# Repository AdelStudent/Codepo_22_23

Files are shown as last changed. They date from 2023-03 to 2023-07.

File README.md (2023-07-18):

## Contents
- `main`: Code for Arduino
- `esp32_easy`: Code for ESP32
- `PCD codepo`: Used to share progress on the PCB
- `Report_final`: Used for writing monthly reports (code to transfer to Arduino)
- `projet codepo`: Used for reading different sensors (code to transfer to Arduino)
- `PythonTest`: Code permettant de vérifier l'envoie de message via le broker Thingstream
- `Modélisation Congo`: Modèle permettant de prédire la consommation en énergie de la cameskin
- `Data Type Cameskin`: Dossier que la CAMESKIN nous a partagé afin comparer si nos moyens de communiquer la data est pertinante

Voici quelques commandes git utiles:

### Download the project
- git clone https://github.com/AdelStudent/Codepo_22_23.git

### Update a downloaded code
- git status
- git pull

### Commit a new code!!
- git add .
- git commit -a -m "Update Message"
- git push

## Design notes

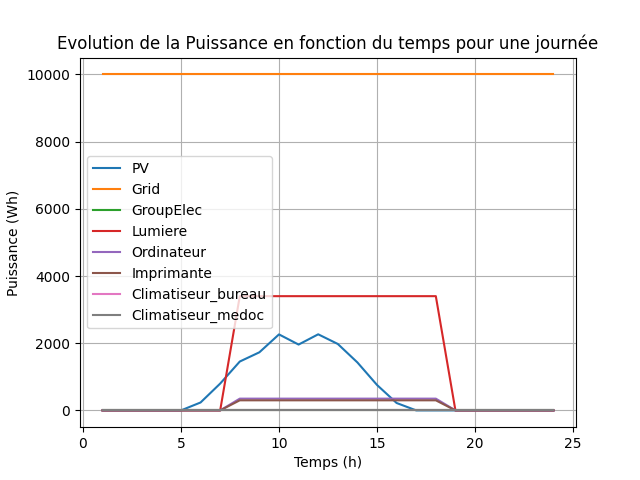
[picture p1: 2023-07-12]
Modélisation Congo/Evolution de la Puissance (1 journée).png

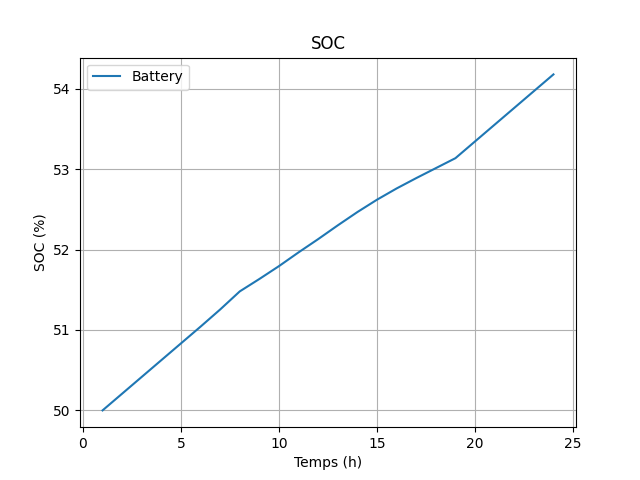
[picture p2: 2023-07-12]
Modélisation Congo/SOC.png

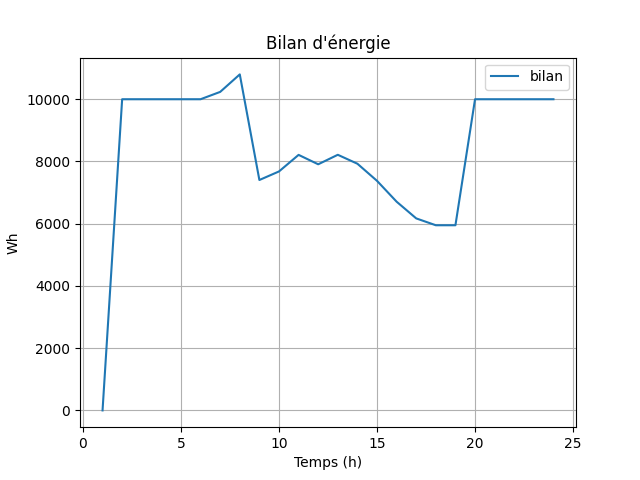
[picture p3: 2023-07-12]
Modélisation Congo/Bilan d'énergie.png

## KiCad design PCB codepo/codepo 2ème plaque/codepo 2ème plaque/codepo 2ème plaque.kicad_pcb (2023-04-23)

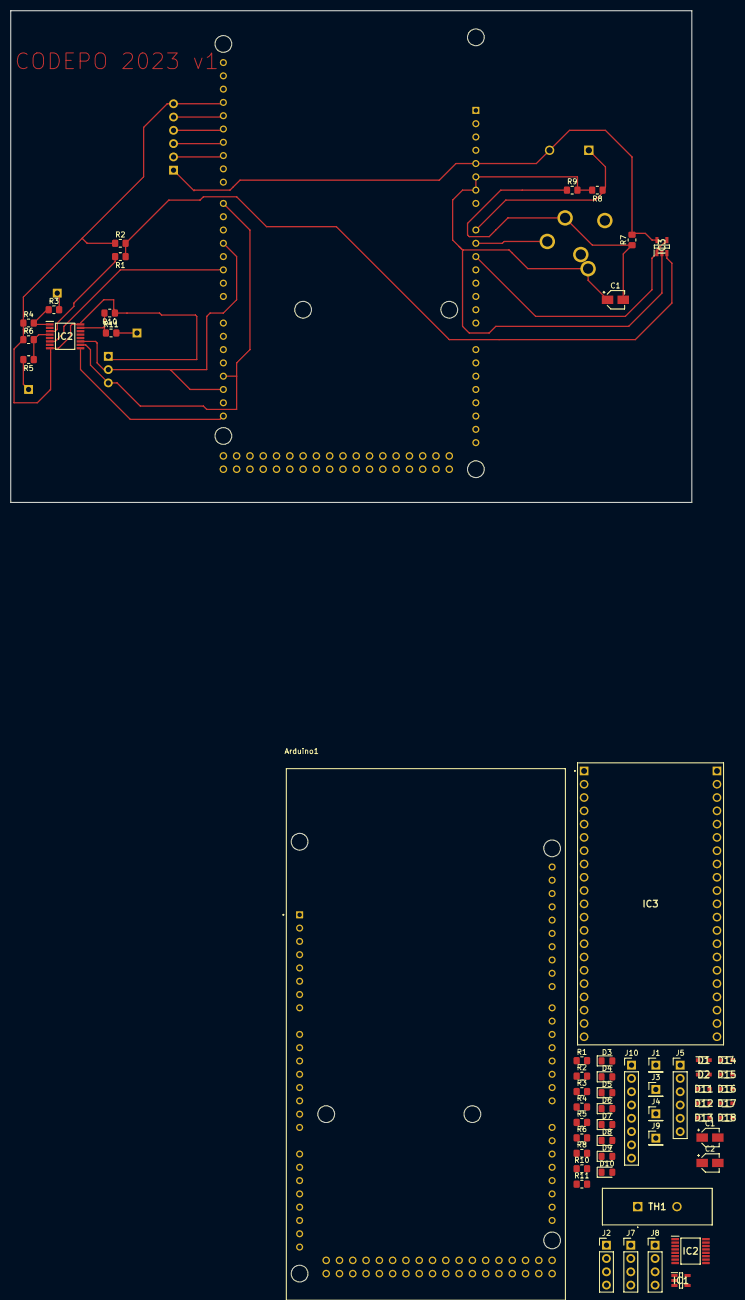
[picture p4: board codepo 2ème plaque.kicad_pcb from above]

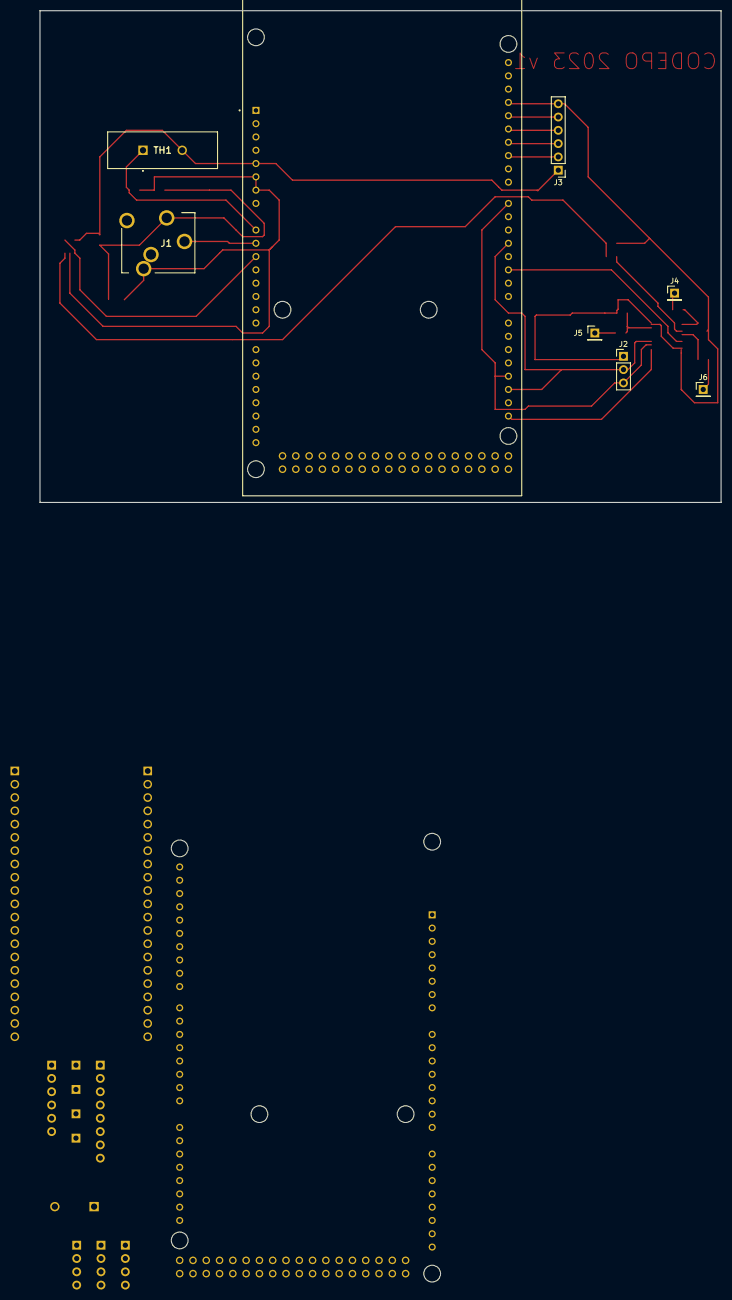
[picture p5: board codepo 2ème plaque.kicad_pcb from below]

Board: 2 copper layers, 130.2 x 94.0 mm, 65 parts (8 on the bottom side), 27 nets.

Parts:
Arduino1, Arduino1#2: DUE; MODULE_A000062
C1: 100 uF; CP_Elec_3x5.3
C1#2, C2: 0.1uF; CP_Elec_3x5.3
D1, D2, D11, D12, D13, D14, D15, D16, D17, D18: D_Schottky; SODFL2513X70N
D3, D4, D5, D6, D7, D8, D9, D10: D_Zener; D_0805_2012Metric_Pad1.15x1.40mm_HandSolder
IC1, IC3: OPA182IDBVR; SOT95P280X145-5N
IC2, IC2#2: TMUX4051PWR; SOP65P640X120-16N
IC3#2: ESP32-S2-Saola-1RI; ESP32S2Saola1RI
J1, J3, J4, J4#2, J5#2, J6, J9: Conn_01x01_Pin; PinHeader_1x01_P2.54mm_Vertical
J1#2: 35RAPC4BH3
J2, J7, J8: Conn_01x04_Pin; PinHeader_1x04_P2.54mm_Vertical
J2#2: Conn_01x03_Pin; PinHeader_1x03_P2.54mm_Vertical
J3#2, J5: Conn_01x06_Pin; PinHeader_1x06_P2.54mm_Vertical
J10: Conn_01x08_Pin; PinHeader_1x08_P2.54mm_Vertical
R1, R1#2: 910kohm; R_0805_2012Metric_Pad1.20x1.40mm_HandSolder
R2, R2#2: 270kohm; R_0805_2012Metric_Pad1.20x1.40mm_HandSolder
R3, R3#2, R10, R10#2, R11, R11#2: 910Kohm; R_0805_2012Metric_Pad1.20x1.40mm_HandSolder
R4, R4#2: 450kohm; R_0805_2012Metric_Pad1.20x1.40mm_HandSolder
R5, R5#2: 910 kohms; R_0805_2012Metric_Pad1.20x1.40mm_HandSolder
R6, R6#2: 300kohm; R_0805_2012Metric_Pad1.20x1.40mm_HandSolder
R7, R8, R8#2, R9: 10kohm; R_0805_2012Metric_Pad1.20x1.40mm_HandSolder
TH1, TH1#2: Thermistor_NTC; B57364S0300M000

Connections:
0: Arduino1.GND1, Arduino1.GND2, C1#2.1, D1.1 (K), D2.1 (K), D3.2 (A), D4.2 (A), D5.2 (A), D6.2 (A), D7.2 (A), D8.2 (A), D9.2 (A), D10.2 (A), D11.1 (K), D12.1 (K), D13.1 (K), D14.1 (K), D15.1 (K), D16.1 (K), D17.1 (K), D18.1 (K), IC1.2 (V-), IC2#2.2 (S6), IC2#2.5 (S5), IC2#2.8 (GND), IC2#2.14 (S1), IC3#2.22 (GND_2), J2.1, J5.6, J7.1, J8.1, J10.8, R2.1, R4#2.1, R6#2.1, R8.2, R10.1
5V: Arduino1.5V_1 (+5V_1), C2.1, J2.4, J5.5, J7.4, J8.4, TH1.2
unnamed: Arduino1.AD0 (ADC0), D3.1 (K), R8.1, TH1.1
unnamed: Arduino1.AD1 (ADC1), D4.1 (K), IC1.1 (OUT), IC1.4 (-IN)
unnamed: Arduino1.AD2 (ADC2), D5.1 (K), J2.2
unnamed: Arduino1.AD3 (ADC3), D6.1 (K), J2.3
unnamed: Arduino1.AD4 (ADC4), D7.1 (K), J8.2
unnamed: Arduino1.AD5 (ADC5), D8.1 (K), J8.3
unnamed: Arduino1.AD6 (ADC6), D9.1 (K), J7.2
unnamed: Arduino1.AD7 (ADC7), D10.1 (K), J7.3
unnamed: Arduino1.2 (D2), D11.2 (A), IC2#2.6 (~EN)
unnamed: Arduino1.16 (D16/TX2), D12.2 (A), IC3#2.26 (U0RXD)
unnamed: Arduino1.17 (D17/RX2), D13.2 (A), IC3#2.25 (GPIO45)
unnamed: Arduino1.7 (D7), Arduino1.18 (D18/TX1), Arduino1.21 (D21/SCL), D1.2 (A), D14.2 (A), D16.2 (A), IC2#2.9 (A2), IC2#2.10 (A1), J10.4
unnamed: Arduino1.4 (D4), Arduino1.19 (D19/RX1), D2.2 (A), D15.2 (A), IC2#2.11 (A0), J10.3
unnamed: Arduino1.52 (D52), D17.2 (A), J5.1
unnamed: D18.2 (A), IC1.3 (+IN), R1#2.1, R2.2
unnamed: C2.2, IC1.5 (V+)
unnamed: IC2#2.3 (D), R1#2.2
unnamed: IC2#2.15 (S2), R10.2, R11.1
unnamed: IC2#2.12 (S3), J9.1
unnamed: IC2#2.1 (S4), R3#2.1, R4#2.2
unnamed: IC2#2.4 (S7), R5.1, R6#2.2
unnamed: C1#2.2, IC2#2.16 (VDD)
unnamed: J1.1, R5.2
unnamed: J3.1, R3#2.2
unnamed: J4.1, R11.2

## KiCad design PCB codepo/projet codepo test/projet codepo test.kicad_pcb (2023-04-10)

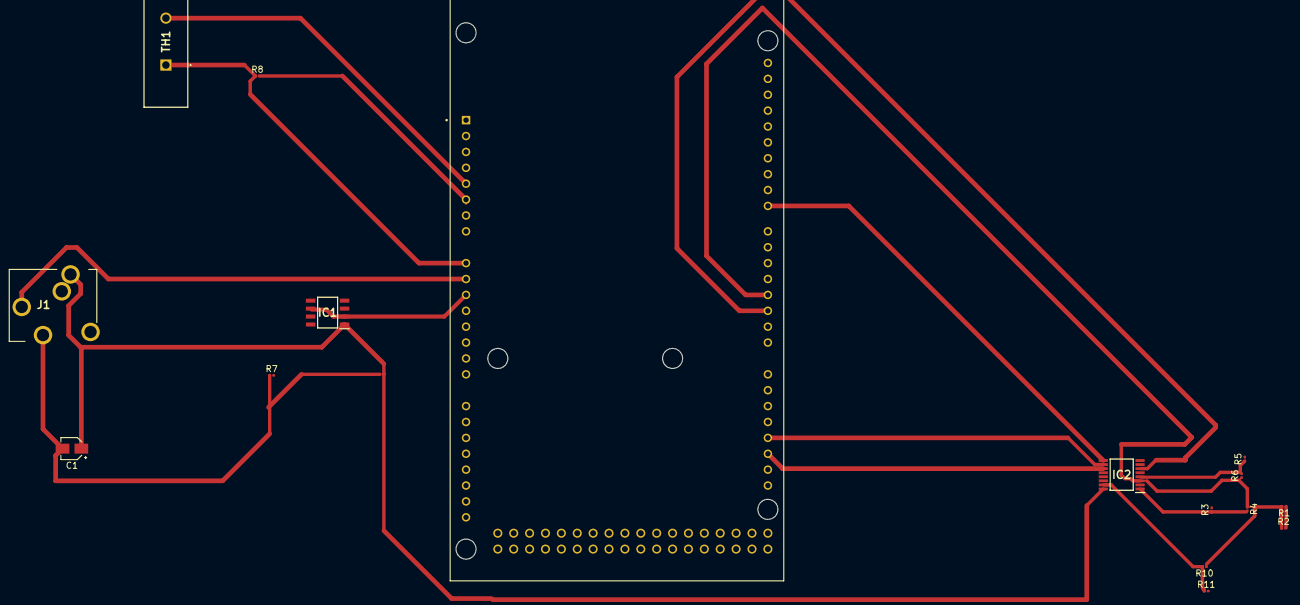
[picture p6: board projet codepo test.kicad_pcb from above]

Board: 2 copper layers, 17 parts (0 on the bottom side), 15 nets.

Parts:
Arduino1: DUE; MODULE_A000062
C1: 100 uF; CP_Elec_3x5.3
IC1: OPA182IDR; SOIC127P600X175-8N
IC2: TMUX4051PWR; SOP65P640X120-16N
J1: 35RAPC4BH3
R1: 910kohm; R_0201_0603Metric
R2: 270kohm; R_0201_0603Metric
R3, R10, R11: 910Kohm; R_0201_0603Metric
R4: 450kohm; R_0201_0603Metric
R5: 910 kohms; R_0201_0603Metric
R6: 300kohm; R_0201_0603Metric
R7, R8, R9: 10kohm; R_0201_0603Metric
TH1: Thermistor_NTC; B57364S0300M000

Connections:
0: Arduino1.3 (D3), IC2.3 (D), R1.2, R2.1, R4.1, R6.1, R10.1
unnamed: Arduino1.5V_1 (+5V_1), IC1.8 (V+), R7.2, TH1.2
unnamed: Arduino1.AD0 (ADC0), R8.1, TH1.1
unnamed: Arduino1.AD1 (ADC1), J1.1
unnamed: Arduino1.AD2 (ADC2), IC1.2 (-IN_A), IC1.6 (-IN_B)
unnamed: Arduino1.2 (D2), IC2.6 (~EN)
unnamed: Arduino1.8 (D8), IC2.9 (A2)
unnamed: Arduino1.7 (D7), Arduino1.18 (D18/TX1), IC2.10 (A1)
unnamed: Arduino1.4 (D4), Arduino1.19 (D19/RX1), IC2.11 (A0)
unnamed: C1.2, J1.5, R7.1, R9.1
unnamed: Arduino1.GND1, C1.1, IC1.1 (OUT_A), IC2.8 (GND), IC2.16 (VDD), J1.2, R8.2, R9.2
unnamed: IC2.15 (S2), R10.2, R11.1
unnamed: IC2.1 (S4), R3.1, R4.2
unnamed: IC2.4 (S7), R5.1, R6.2
unnamed: R1.1, R2.2

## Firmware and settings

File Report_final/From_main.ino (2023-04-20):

void SD_init(int *init_flag_SD){ //Le pointeur initial est à 0 si il y a une carte -> update to 1
  // Le pointeur est appelé flag car il indique si l'initialisation s'est fait correctement
  //print_variable("CS_PIN",CS_PIN);
  if(SD.begin(CS_PIN)==true){
    //Serial.println("La carte SD a bien démarrée");
    *init_flag_SD = 1;
  }
  else{
    Serial.println("La carte SD n'a PAS ete trouve!");
  }
}


void delete_file(String filename){
  //Si le file existe, on le supprime (utile pour les tests)
  if(verify_file_existing(filename)){ //vérifie d'abord que le fichier existe sur la carte 
  // correpond à une boucle if True
    SD.remove(filename);
    Serial.println("Report a été nettoyé");
  }
}
bool verify_file_existing(String filename){ //filename to be checked 
  //Si le file existe, on le supprime (utile pour les tests)
  if(SD.exists(filename)){
    Serial.println("Le file existe!");
    return true; //retourne une réponde boolean 
  }else{
    Serial.println("Le file n'existe pas.");
    return false; //retourne une autre réponse de boolean 
  }
}

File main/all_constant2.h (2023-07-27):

/*
Pour la personne qui va lire ce code:
    Ce fichier en .h ne sera appelé que par le header file "z_all_constantes". Cette méthode nous a permis de travailler en parallèle
    tout en faisant un merge aisé ainsi que nous permettant de nous y retrouver rapidement.
*/

//ECRAN LCD
#include "Wire.h"
#include "LiquidCrystal_I2C.h"

LiquidCrystal_I2C LCD(0x27,16,2);

//PINS
  //A0 -> thermistance 
  //A1 -> mesure courant 
  //A2 -> calibration capteur de courant 
  //A3 -> sortie du multiplexeur 
  //2 -> ENpin du multiplexeur 
  //4 -> Decision de channel du multi
  //7 -> Decision de channel du multi
  //8 -> Decision de channel du multiSOC_init
//___________________THERMISTANCE___________________//
#define Tsensor A0

float A = 2.51e-03, B =1.039e-04, C = 0; //Coef. permettant de déterminer la température grâce 
#define THERMISTOR 10000 // résistance nominale de la thermistor, 10 kOhm
#define Vcc 3.3// tension d'entrée= 3.3V


//_________________Capteur COURANT_________________//
  //AC & DC Current Sensor with LCD By Solarduino 
  //AC & DC current captor -> HSTS016L Hall effect split core current transformer
  //The current measured is the Root Mean Square (RMS) value.

int decimalPrecision = 4; //Precision -> nombre de décimales 

//_________________PINS
int currentAnalogInputPin = A1;    // Pin to measure Current Value -> celle connecté au sensor [JAUNE]
int calibrationPin = A2;         // Pin to calibrate offset middle value -> calibre le senseur [BLANC]

//_________________Variables
float manualOffset = 0;  //0.26 -0.37  0.280    // Key in value to manually offset the initial value -> Pourrait l'utiliser si on arrive vraiment pas à ce qu'on veut 
// pour ajuster manuellement la lecture du courant initiale si nécessaire 
float mVperAmpValue = 31.25; //31.25 -20.83    // mVperAmp = maximum voltage range (in milli volt) / current rating of CT
//Specifie le mV/A puissance du transformateur de courant 
// For a 20A Hall-Effect Current Transformer rated at 20A, 2.5V +/- 0.625V, mVperAmp will be 625 mV / 20A = 31.25mV/A 

float supplyVoltage = 3300;        // Analog input pin maximum supply voltage, Arduino Uno or Mega is 5000mV while Arduino Nano or Node MCU is 3300mV
// Interessant de noter que toutes les données sont en mV
//Maximum tension d'entrée aux pins analogue de l'Arduino  
float offsetSampleRead = 0;        // to read the value of a sample for offset purpose later 
//Pour lire une valeur échantillon pour déterminer le décalage de/par rapport calibration 
float currentSampleRead  = 0;      // to read the value of a sample including currentOffset1 value
//Utiliser pour lire la valeur de courant pour chaque échantillon 
float currentLastSample  = 0;      //to count time for each sample. Technically 1 milli second 1 sample is taken 
//Pour tracker le temps depuis que le dernier échantillon a été pris 
float currentSampleSum   = 0;      // accumulation of sample readings 
//Accumulate les valeurs échantillons 
float currentSampleCount = 0;      // to count number of sample. 
float currentMean ;                // to calculate the average value from all samples, in analog values
float RMSCurrentMean ;             // square roof of currentMean, in analog values  
float FinalRMSCurrent ;            // the final RMS current

//_____CAPTEUR DE TENSION/MULTIPLEXEUR___________//
  // basé sur le code https://www.aranacorp.com/fr/utilisation-dun-multiplexer-avec-arduino/
  
//_________________CONSTANTS
#define number_of_mux 1 //définition du nombre de multiplexeur
#define numOfMuxPins number_of_mux * 8 //définition du nombre de pins totals (en fonction du nombre de multiplexeur)

//_________________PINS
  //Pins qui indique les portes à ouvrir sur l'Arduino
#define enPin 2 //Quand cette pin est high, tous les switchs sont off 
#define channelA0 4 //pin A0 du mult (11 sur mult) -> pin 4 digital de l'Arduino
#define channelA1 7 //pin A1 du mult (10 sur mult) -> pin 7 digital de l'Arduino
#define channelA2 8 // pin A2 du mult (9 sur mult) -> pin 8 digital de l'Arduino

//Tension de sortie que l'on veut mesuré après le montage avec diviseur résistif 
#define pinout A3  // pin analogue A1

float measured_value[] = {0,0,0,0,0,0,0,0}; //vecteur qui prend les valeurs 
//i ème position du vecteur sera égale à la valeur mesuré sur la ième porte 

//Paramètre
const int D  = 3; //Drain pin, allows to send/receive signals. Connecté selon les indications du site

//_________________PARAMETRES PROTOTYPE
float R1 = 913, R2 = 280;//en kohm 
// à corriger avec ce qui est lu par le multimètre : pas 907 et 270 mais 913 et 280

//#define Vcc 5.0 // tension d'entrée= 5.0V
//=> Déjà définie pour la thermistance
//De l'année passée
int nbSamples = 100;
double mvPerI_20 = 31.25;
double offset_20 = 0.36;
double mvPerI_100 = 6.25;
double offset_100 = 1.6;
double mvPerI_30 = 20.83;
double offset_30 = 0.515;
double offset_30_bat020 = 0.515;//0.16
double offset_30_res020 = 0.515;//0.27
double offset_30_ppv020 = 0.515;//0.31

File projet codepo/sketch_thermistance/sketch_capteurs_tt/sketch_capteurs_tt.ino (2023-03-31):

//code pour la tension
float R1 = 907, R2 = 270;//en kohm
float A = 8.79e-03, B = -1.1e-03, C = 6.46e-06;
#define THERMISTOR 10000 // résistance nominale de la thermistor, 10 kOhm

#define sensor A0
#define Vcc 5.0 // tension d'entrée= 5V
#define pinout A2
const int s0Pin = 2; // connect to S0 pin of TMUX1108
const int s1Pin = 3; // connect to S1 pin of TMUX1108
const int s2Pin = 4; // connect to S2 pin of TMUX1108
const int s3Pin = 5; // connect to S3 pin of TMUX1108
#define pinout A2// connect to the Vo pin of TMUX1108
#include <Wire.h>
#include <EmonLib.h>

EnergyMonitor emon1;
int tension = 9.38; //itier la tension (calculer au préalable avec un multimetre)
#define pin_sct A1// pin A1 =connexion au capteur

void setup() {
  Serial.begin(9600);
  emon1.current(pin_sct, 29);
  pinMode(sensor, INPUT);
  pinMode(pinout, INPUT);
  pinMode(s0Pin, OUTPUT);
  pinMode(s1Pin, OUTPUT);
  pinMode(s2Pin, OUTPUT);
  pinMode(s3Pin, OUTPUT);
  pinMode(pinout, INPUT);

  // set initial state for multiplexer pins
  digitalWrite(s0Pin, LOW);
  digitalWrite(s1Pin, LOW);
  digitalWrite(s2Pin, LOW);
  digitalWrite(s3Pin, LOW);
}

void loop() {
  // read Vo from currently selected input
  double Vo = analogRead(pinout) / 1023.0 * 3.3;
  double Vin = Vo * (R1 + R2) / R2;
  Serial.print("vout=");
  Serial.print(Vo);
  Serial.print("V");

  Serial.print("vin=");
  Serial.print(Vin);
  Serial.println("V");
  // select next input
  int s3 = digitalRead(s3Pin);
  int s2 = digitalRead(s2Pin);
  int s1 = digitalRead(s1Pin);
  int s0 = digitalRead(s0Pin);

  if (s3 == LOW && s2 == LOW && s1 == LOW && s0 == LOW) {
    digitalWrite(s0Pin, HIGH);
  } else if (s3 == LOW && s2 == LOW && s1 == LOW && s0 == HIGH) {
    digitalWrite(s0Pin, LOW);
    digitalWrite(s1Pin, HIGH);
  } else if (s3 == LOW && s2 == LOW && s1 == HIGH && s0 == LOW) {
    digitalWrite(s1Pin, LOW);
    digitalWrite(s2Pin, HIGH);
  } else if (s3 == LOW && s2 == LOW && s1 == HIGH && s0 == HIGH) {
    digitalWrite(s2Pin, LOW);
    digitalWrite(s3Pin, HIGH);
  } else if (s3 == LOW && s2 == HIGH && s1 == LOW && s0 == LOW) {
    digitalWrite(s1Pin, HIGH);
    digitalWrite(s2Pin, LOW);
    digitalWrite(s3Pin, LOW);
  } else if (s3 == LOW && s2 == HIGH && s1 == LOW && s0 == HIGH) {
    digitalWrite(s0Pin, HIGH);
    digitalWrite(s2Pin, LOW);
    digitalWrite(s3Pin, LOW);
  } else if (s3 == LOW && s2 == HIGH && s1 == HIGH && s0 == LOW) {
    digitalWrite(s0Pin, LOW);
    digitalWrite(s1Pin, HIGH);
    digitalWrite(s3Pin, LOW);
  } else if (s3 == LOW && s2 == HIGH && s1 == HIGH && s0 == HIGH) {
    digitalWrite(s0Pin, HIGH);
    digitalWrite(s1Pin, HIGH);
    digitalWrite(s2Pin, HIGH);
    digitalWrite(s3Pin, LOW);
  } else if (s3 == HIGH && s2 == LOW && s1 == LOW && s0 == LOW) {
    digitalWrite(s2Pin, HIGH);
    digitalWrite(s1Pin, LOW);
    digitalWrite(s0Pin, LOW);
  } else if (s3 == HIGH && s2 == LOW && s1 == LOW && s0 == HIGH) {
    digitalWrite(s3Pin, LOW);
    digitalWrite(s1Pin, LOW);
    digitalWrite(s0Pin, HIGH);
  } else if (s3 == HIGH && s2 == LOW && s1 == HIGH && s0 == LOW) {
    digitalWrite(s2Pin, HIGH);
    digitalWrite(s0Pin, LOW);
  } else if (s3 == HIGH && s2 == LOW && s1 == HIGH && s0 == HIGH) {
    digitalWrite(s3Pin, LOW);
    digitalWrite(s0Pin, HIGH);
  } else if (s3 == HIGH && s2 == HIGH && s1 == LOW && s0 == LOW) {
    digitalWrite(s3Pin, LOW);
    digitalWrite(s1Pin, HIGH);
  } else if (s3 == HIGH && s2 == HIGH && s1 == LOW && s0 == HIGH) {
    digitalWrite(s2Pin, LOW);
    digitalWrite(s1Pin, HIGH);
    digitalWrite(s0Pin, HIGH);
  } else if (s3 == HIGH && s2 == HIGH && s1 == HIGH && s0 == LOW) {
    digitalWrite(s3Pin, LOW);
    digitalWrite(s2Pin, HIGH);
    digitalWrite(s0Pin, LOW);
  } else if (s3 == HIGH && s2 == HIGH && s1 == HIGH && s0 == HIGH) {
    digitalWrite(s3Pin, HIGH);
  }
  int sensorvalue = analogRead(sensor);
  float Vx = sensorvalue * (5.0 / 1023.0);
  float V = Vcc - Vx;
  float I = Vx / 10000;
  float R = V / I;
  Serial.print("R=");
  Serial.print(R);
  Serial.print("ohm");
  Serial.print(", t=");

  float steinhart;
  float T;
  steinhart = 1 / (A + (B * log(R)) + (C * pow((log(R)), 3)));
  T = steinhart - 273.15; //pour tourner la température en degré
  Serial.print(T);
  Serial.println("°C");
  double Irms = emon1.calcIrms(1480);
  Serial.print("Courant:"); //(en ampère)
  Serial.println(Irms);


  delay(1000);
}

////This code uses digital pins 2-5 to control the select lines of the TMUX1108 multiplexer
////and analog pin A0 to read the Vo from the selected input. The `loop()` function cycles
////through all 16 input channels of the multiplexer, reading the Vo from each one in turn.
////The debounce delay of 10ms helps to reduce noise and stabilize the Vo readings.

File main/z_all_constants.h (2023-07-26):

/*
Pour la personne qui va lire ce code:
    Ce header file (.h) permet d'avoir un fichier aillant tous les includes/constantes nécessaires au bon déroulement de notre protoype.
    Cela permet surtout une lecture plus aisée du projet.
*/
#include "all_constant2.h"

#include <SD.h>
#include <SPI.h>
#include "TimeLib.h"
#include "time.h"

#include "RTClib.h" //Downloaded from the follwoing git : https://github.com/adafruit/RTClib
                    //Also needed this one : https://github.com/adafruit/Adafruit_BusIO/tree/master
#include <RTCDue.h>



#include <LiquidCrystal.h>

#include <stdlib.h>



////////////////////////////////////////////////////////////////////
//Initialisation des variables                                    //
////////////////////////////////////////////////////////////////////

//_____________________Kalman Variables___//

//_____________________Multi Threading version Wish___//
unsigned long lastMeasurementTime = 0; // variable to store the last time measurement
unsigned long lastHearingTime = 0; // variable to store the last time we heard Arduino
unsigned long lastReportWriting = 0; // variable to store the last time we wrote into the Arduino
unsigned long lastAskingTime = 0; // variable to store the last time we asked IP address to ESP32
unsigned long lastUpdateFilter = 0; //variable to store the last time Kalman Filter parameters update
unsigned long last_warning_message = 0; //variable to store the last time we send potentially send a Warning Mail



//_____________________Thingstream___________________//
unsigned long mytime; //Permet de connaitre le temps d'attente pour recevoir une réponde du thingStream
int init_flag = 0;  //Permet de savoir si toutes les étapes de l'initialisation du Thingstream sont okay
bool already_publish = false; //Variable tests

//_____________________SD Card______________________//
File myFile;  //Objet permettant l'ouverture de fichiers en accès w et/ou r
File myReport;  //Par souçis de cohérence des parties de codes, on garde ces Files
File file;  //Par soucis de cohérence des parties de codes, on garde les 3 files (myFile/myReport/file)
#define CS_PIN 53 //Pin utilisée pour transmettre la data à la carte SD
int init_flag_SD = 0;


//_____________________ESP32______________________//
String esp32_ip = "";
bool answering_mode = false; //It allows to block send any queries to ESP32 if this mode is activated
unsigned long answering_mode_chrono = 0; // variable to store the time of the last time we asked IP address to ESP32

//_____________________Measures______________________//
// Define the input and output pins for the current sensors
#define INPUT_CURRENT_PIN A0
#define OUTPUT_CURRENT_PIN A1
// Define the sample interval (in milliseconds) and the number of samples to take
#define SAMPLE_INTERVAL 1000
#define NUM_SAMPLES 10

//_______________Coulomb Counting___________________//
float SOC_init = 0.97; // We only need a start point

// Define a variable to keep track of the last sample time
unsigned long lastSampleTime = 0;

//_____________________CLOCK________________________//
RTCDue Arduino_rtc(XTAL); //Arduino RTC
RTC_DS3231 rtc; //DS3231 RTC

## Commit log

2023-07-07 Add files via upload
    Checking periodically if the ESP32 got disconnected to the Wifi.
2023-07-08 Vcc Tension
2023-07-08 Réajustement des résistances
2023-07-10 Nouvel fonction de mesure de courant
2023-07-10 Constantes pour le capteur de courant
2023-07-13 Resistance des diviseurs résistifs measure.ino
2023-07-13 Arduino answering_mode + corrections
    [SOC.ino, arduino_to_ESP32.ino, communicate_with_arduino.ino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]
2023-07-13 Bug de synchro corrigée
    [arduino_to_ESP32.ino, asynch_server.ino, communicate_with_arduino.ino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]
2023-07-16 Ajout du dossier 'Data Type Cameskin'
    [SAV2_220910_115712_1384.csv, SAV2_220910_115748_6098.csv, SAV2_220910_115823_5068.csv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]
2023-07-16 Add files via upload
    Ajout du dossier 'Data Type Cameskin'
    [SAV2_220910_115712_1384.csv, SAV2_220910_115748_6098.csv, SAV2_220910_115823_5068.csv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]
2023-07-17 Function Test Calibration
    Fonction permettant d'afficher ce qu'il se passe sur le réseau au niveau courant
2023-07-17 Update current measure.ino
2023-07-18 Modif Pour ESP32 LocalTime
2023-07-19 tension batterie par batterie.ino
